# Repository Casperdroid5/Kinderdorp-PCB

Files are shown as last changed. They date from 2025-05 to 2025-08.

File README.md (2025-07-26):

# Kinderdorp PCB 👍

An interactive educational PCB designed for children to learn electronics through hands-on experimentation with LEDs, sensors, and programming.

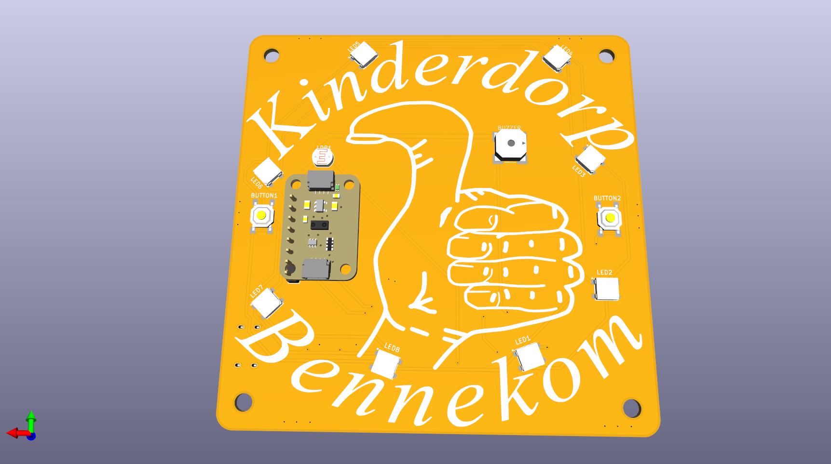
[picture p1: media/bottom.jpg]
Kinderdorp PCB Top

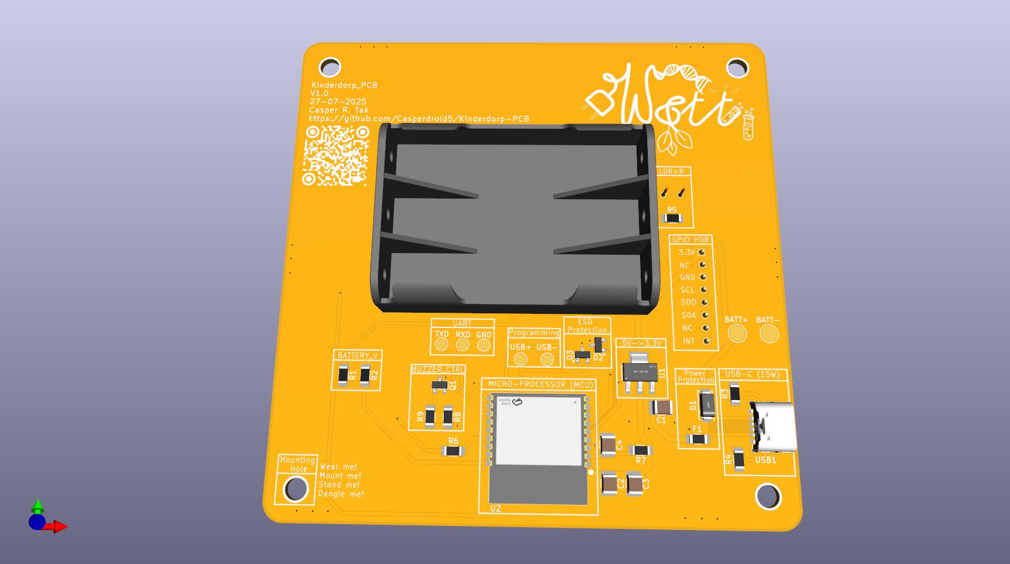
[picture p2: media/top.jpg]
Kinderdorp PCB Bottom


## 📋 Overview

The Kinderdorp PCB is an ESP32-C3 based learning platform featuring addressable RGB LEDs, user input buttons, sensors, and multiple power options. The board includes fun visual elements and is designed to be both educational and engaging for young learners.

## ✨ Features

### 🎯 Core Components
- **ESP32-C3-WROOM-02-N4** microcontroller (4MB Flash)
- **8x WS2812B** addressable RGB LEDs arranged in a creative pattern
- **2x Tactile buttons** for user interaction
- **Light sensor (LDR)** for ambient light detection
- **Buzzer** for audio feedback
- **USB-C connector** for power and programming

### 🔋 Power Options
- **USB-C** power input (5V)
- **Dual CR2032** coin cell battery holders
- **3x AAA** battery pack option
- **AMS1117-3.3V** voltage regulator
- Battery voltage monitoring circuit

### 🔌 Connectivity
- **8-pin header** for expansion and prototyping
- **Programming pins** for development
- **Test points** for debugging

## 🔧 Technical Specifications

| Component | Specification |
|---|---|
| **Microcontroller** | ESP32-C3-WROOM-02-N4 (4MB) |
| **Operating Voltage** | 3.3V |
| **Power Input** | 5V via USB-C or 3-6V battery |
| **LEDs** | 8x WS2812B RGB (5050 package) |
| **Buttons** | 2x DTSM-61R tactile switches |
| **Buzzer** | KSSGK4B16-20 |
| **Light Sensor** | LDR07 photoresistor |
| **PCB Dimensions** | ~100mm x 100mm |

## 📍 Pin Mapping

### GPIO Assignments
```
GPIO0  - Programming/Boot button
GPIO1  - UART TX (programming)
GPIO3  - UART RX (programming)  
GPIO4  - User Button 1
GPIO5  - RGB LED Data Out
GPIO6  - SDA (I2C)
GPIO7  - SCL (I2C)
GPIO8  - User Button 2
GPIO9  - Buzzer Control
GPIO10 - Light Sensor (ADC)
GPIO18 - Battery Voltage Monitor
GPIO19 - RGB LED Data In
```

### LED Chain Order
The 8 WS2812B LEDs are connected in series:
`LED1 → LED2 → LED3 → LED4 → LED5 → LED6 → LED7 → LED8`

## 🚀 Getting Started

### Prerequisites
- **Arduino IDE** or **PlatformIO**
- **ESP32 board package** installed
- **FastLED** or **Adafruit NeoPixel** library for LED control

### Hardware Setup
1. **Power the board** via USB-C or install batteries
2. **Connect** USE the breakout pads USB+ and USB- or UART to program the board
3. **Install** any additional components if using expansion header

### Basic Programming Example

```cpp
#include <FastLED.h>

#define LED_PIN 19
#define NUM_LEDS 8
#define BUTTON1_PIN 4
#define BUTTON2_PIN 8
#define BUZZER_PIN 9
#define LDR_PIN 10

CRGB leds[NUM_LEDS];

void setup() {
  FastLED.addLeds<WS2812B, LED_PIN, GRB>(leds, NUM_LEDS);
  pinMode(BUTTON1_PIN, INPUT_PULLUP);
  pinMode(BUTTON2_PIN, INPUT_PULLUP);
  pinMode(BUZZER_PIN, OUTPUT);
}

void loop() {
  // Rainbow effect
  for(int i = 0; i < NUM_LEDS; i++) {
    leds[i] = CHSV(i * 32, 255, 255);
  }
  FastLED.show();
  delay(100);
}
```

## 🎓 Educational Applications

### Beginner Projects
- **LED Patterns** - Create colorful light sequences
- **Button Response** - Interactive games with button presses
- **Light Detection** - Automatic brightness control
- **Sound Effects** - Musical patterns with the buzzer

### Intermediate Projects
- **Simon Says Game** - Memory game using LEDs and buttons
- **Light Meter** - Display ambient light levels
- **Digital Pet** - Virtual pet with LED expressions
- **Alarm Clock** - Wake-up light with buzzer

### Advanced Projects
- **WiFi Connectivity** - IoT integration and remote control
- **Sensor Dashboard** - Environmental monitoring
- **Interactive Art** - Motion-responsive installations
- **Educational Games** - Programming challenges

## 🔋 Power Management

### Battery Life Optimization
- Use **deep sleep mode** when inactive
- **Dim LEDs** or turn off when not needed
- **Monitor battery voltage** (GPIO18) for low battery warnings

### Battery Voltage Monitoring
```cpp
float getBatteryVoltage() {
  int rawValue = analogRead(18);
  // Voltage divider: 6V→3V, 4.5V→2.25V, 3V→1.5V, 2V→1V
  return (rawValue / 4095.0) * 3.3 * 2.0;
}
```

## 🛠️ Assembly Notes

### Battery Installation
- **Option 1**: Install 2x CR2032 coin cells in BT1 and BT2
- **Option 2**: Connect 3x AAA battery pack to BATTPACK1
- **Do not** install both battery options simultaneously (should not be possible if PCB is asssembled correctly)

## 🎨 Design Features

The PCB includes playful design elements:
- **Artistic patterns** and decorative silkscreen
- **Child-friendly** component layout
- **Clear labeling** for educational purposes
- **Robust construction** for classroom use

## 📄 License

This project is released under the [MIT License](LICENSE). Feel free to use, modify, and distribute for educational purposes.

## 👨‍💻 Author

**Casper R. Tak**

---

*Kinderdorp PCB - Making electronics fun and accessible for young (and older) minds! 🌟*

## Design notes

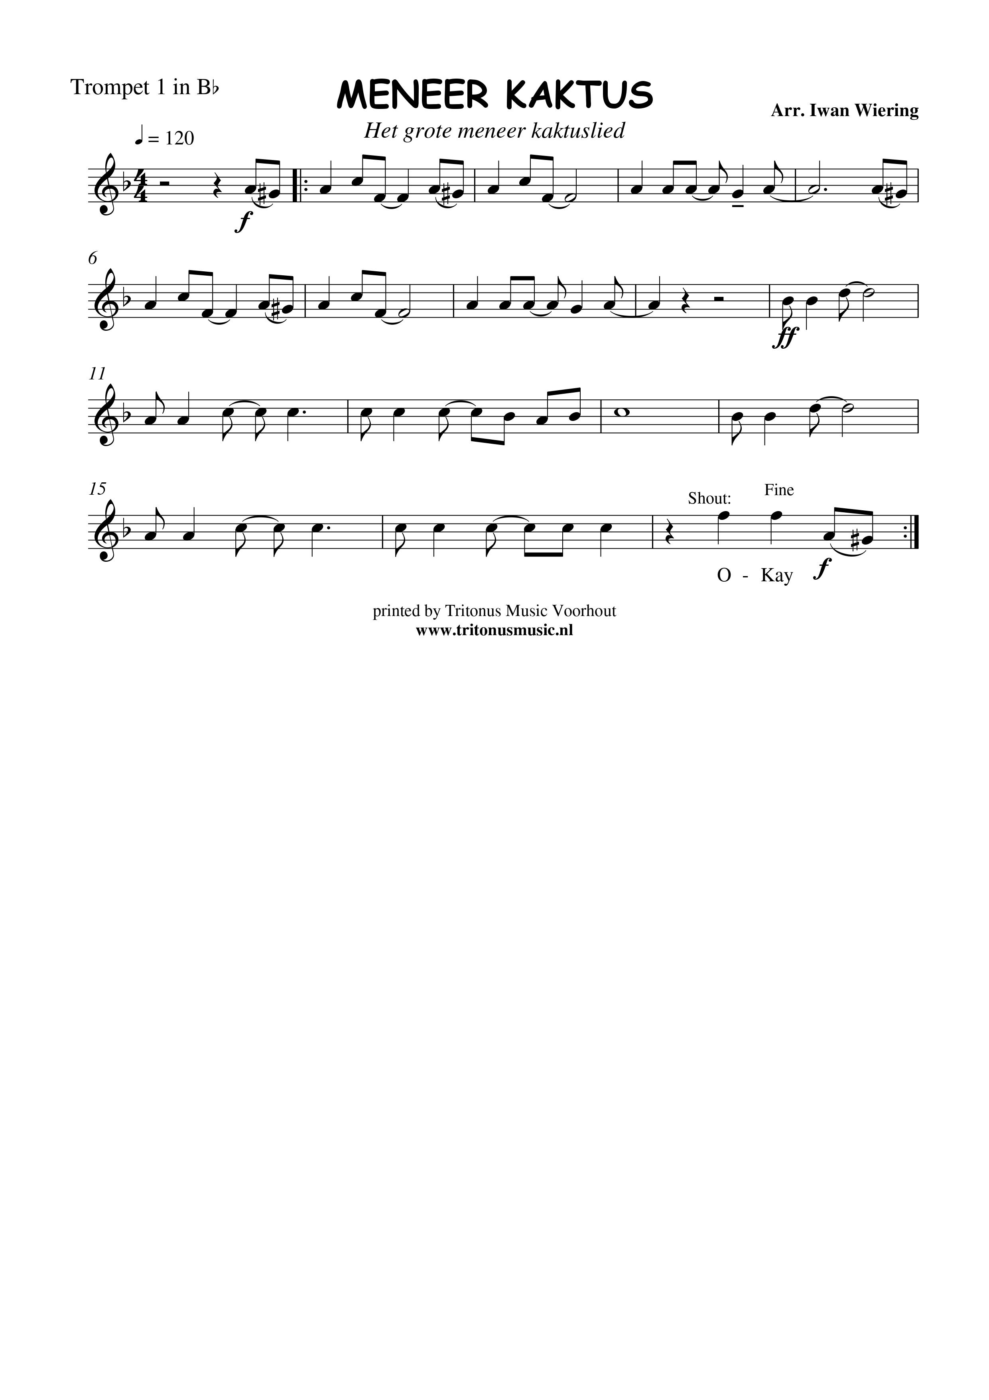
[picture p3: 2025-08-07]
media/Kinderdorp lied/Meneer-kaktus-Trompet-1-in-Bb.jpeg

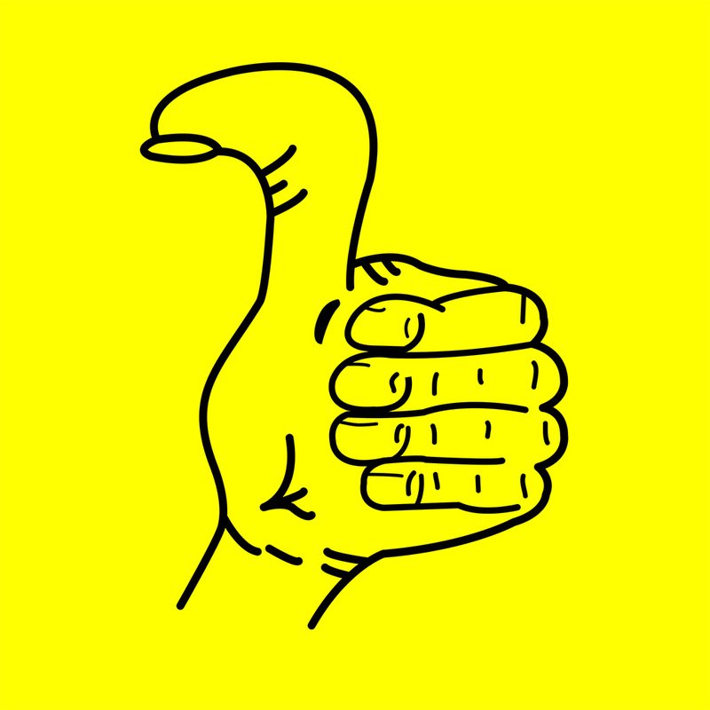
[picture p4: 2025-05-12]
media/kinderdorp logo no text.jpg

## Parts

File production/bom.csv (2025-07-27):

Designator | Footprint | Quantity | Value | LCSC Part #
BATT+ | TestPoint_Pad_D3.0mm | 1 | ~
BATT- | TestPoint_Pad_D3.0mm | 1 | TestPoint_Alt
BT1:, BT2: | BAT-SMD_MY-2032-12 | 2 | MY-2032-12 | C964833
BUTTON1, BUTTON2 | KEY-SMD_4P-L6.2-W6.2-P4.50-LS9.0 | 2 | DTSM-61R-V-T/R | C224977
C1, C3 | 1210 | 2 | 47uF 10V
C2 | 1210 | 1 | 100nF 50V
C4 | 1210 | 1 | 10uF 25V
D1 | SMA_L4.4-W2.6-LS5.0-RD | 1 | 1N5819_C437199 | C437199
D2, D3 | SOT-23 | 2 | SM712_SOT23
F1 | 1206 | 1 | Fuse_Small 2A
GND, RXD, TXD, USB+, USB- | TestPoint_Pad_D2.0mm | 5 | TestPoint_Probe
HDR1 | PinHeader_1x08_P2.54mm_Vertical | 1 | Conn_01x08
LDR1 | R_LDR_5.1x4.3mm_P3.4mm_Vertical | 1 | LDR07
LED1, LED2, LED3, LED4, LED5, LED6, LED7, LED8 | LED-SMD_4P-L5.0-W5.0-BL_TC5050RGB | 8 | WS2812B
LS1 | KSSGK4B16-20 | 1 | KSSGK4B16-20
Q1 | SOT-23-3_L2.9-W1.3-P1.90-LS2.4-BR | 1 | 2N7002_C306856
R1, R2, R7, R8 | 1206 | 4 | 10k
R3, R4 | 1206 | 2 | 5k1
R5 | 1206 | 1 | 5k
R6, R9 | 1206 | 2 | 200
U1 | SOT-223-4_L6.5-W3.5-P2.30-LS7.0-BR | 1 | AMS1117-3.3_C347222 | C347222
U2 | BULETM-SMD_ESPRESSIF_ESP32-C3-WROOM-02-N4-4MB | 1 | ESP32-C3-WROOM-02-N4(4MB)
USB1 | TYPE-C-SMD_TYPE-C-6P_5 | 1 | TYPE-C 6P(073) | C668623

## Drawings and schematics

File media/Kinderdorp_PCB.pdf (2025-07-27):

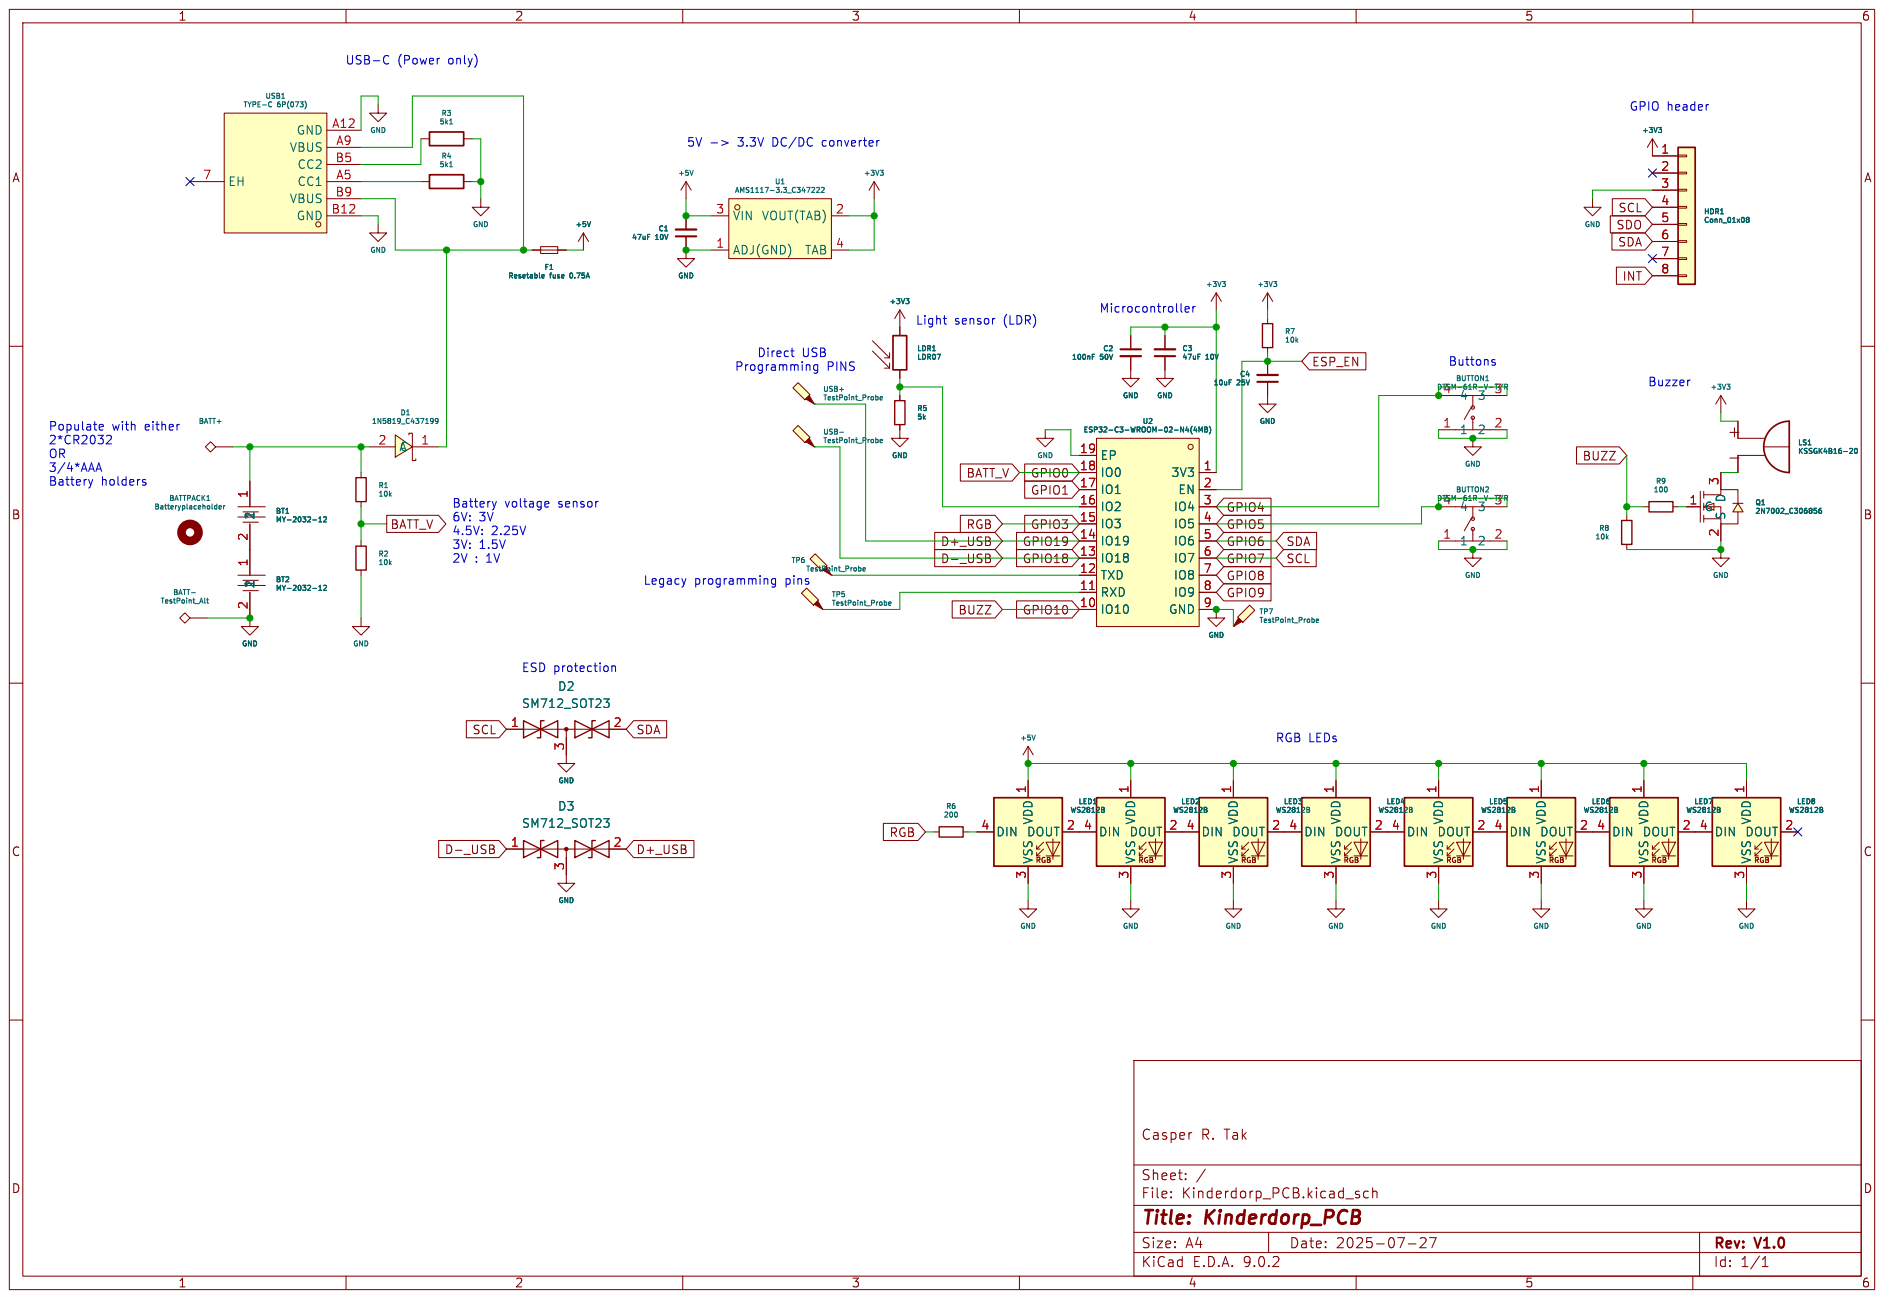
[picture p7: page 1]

5k1 GND B12 VBUS B9 CC1 A5 CC2 B5 VBUS A9 GND A12 EH 7

File: Kinderdorp_PCB.kicad_sch Sheet: / Casper R. Tak

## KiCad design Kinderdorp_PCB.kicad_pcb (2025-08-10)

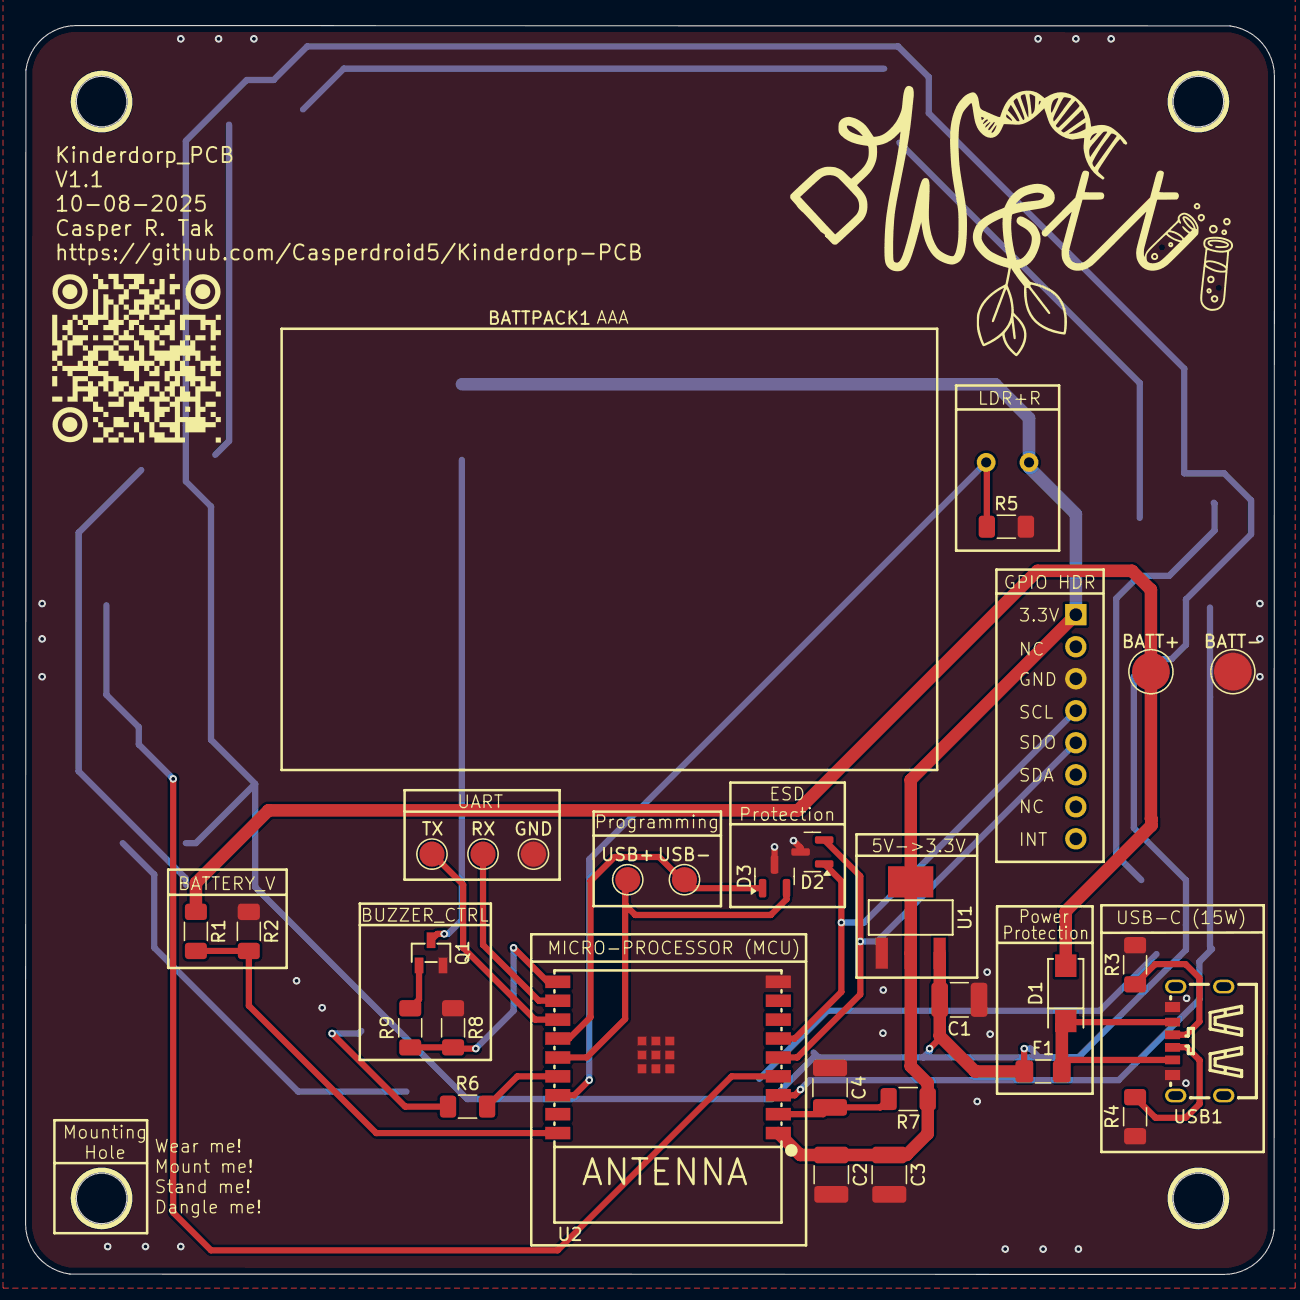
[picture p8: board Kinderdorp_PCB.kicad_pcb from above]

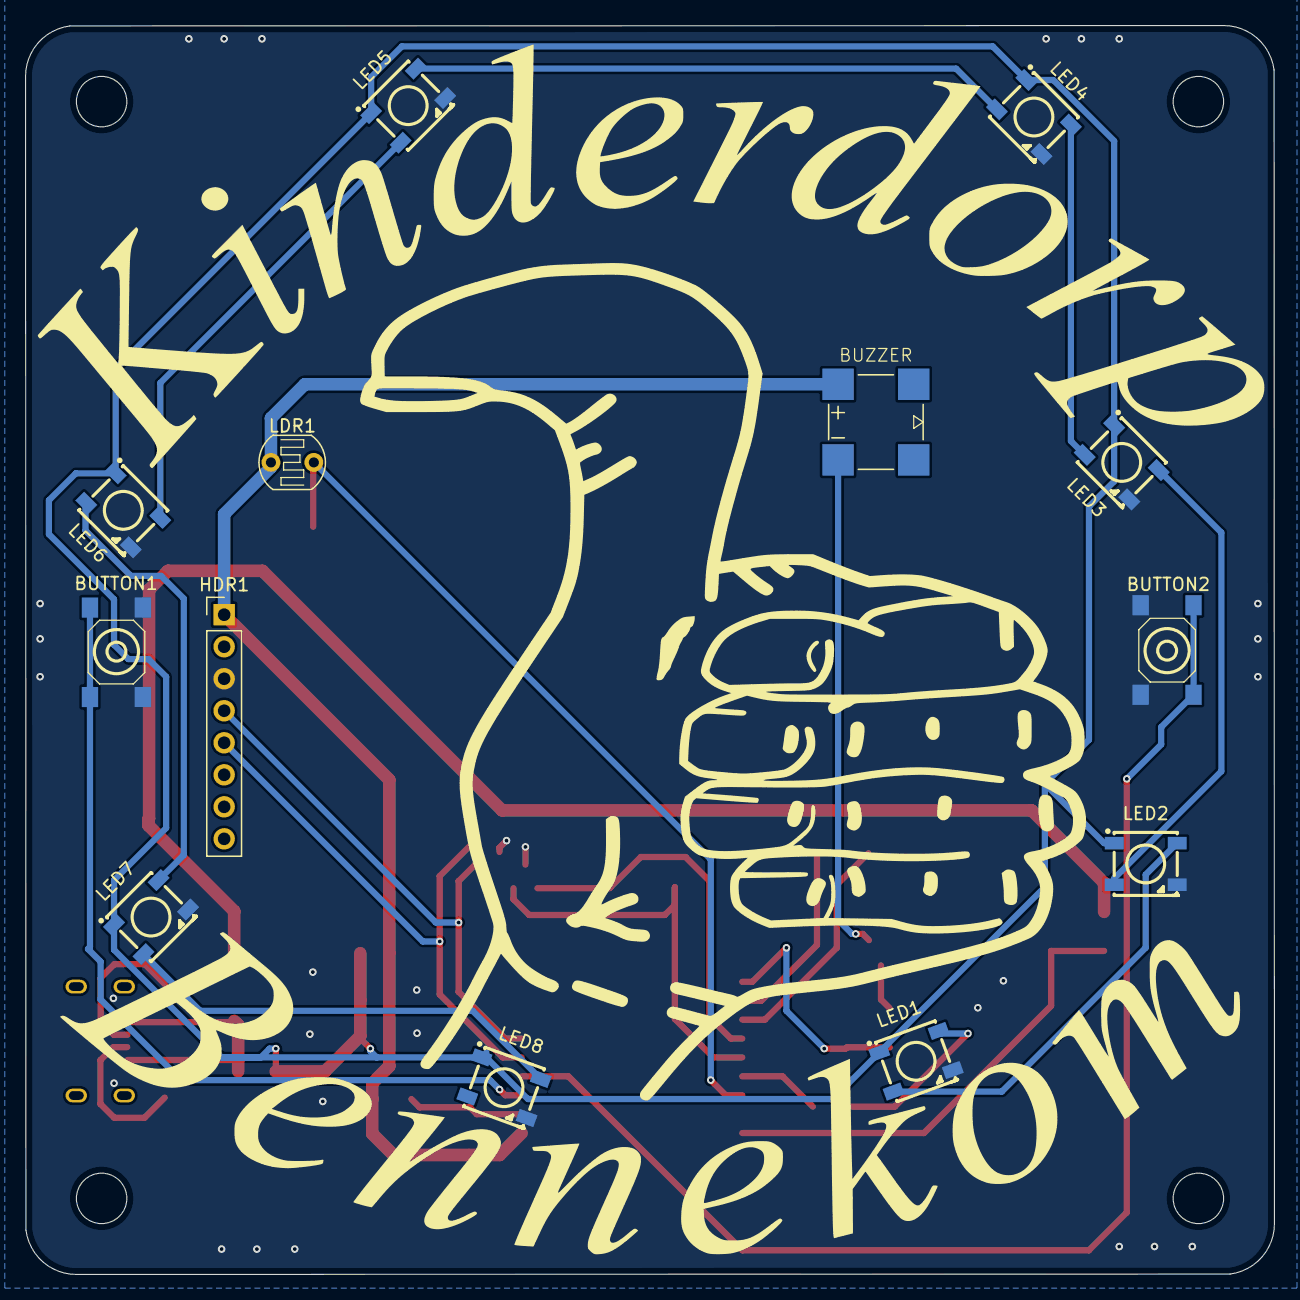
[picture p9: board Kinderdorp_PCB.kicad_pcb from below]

Board: 2 copper layers, 99.1 x 99.1 mm, 42 parts (13 on the bottom side), 30 nets.

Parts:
BATT+: TestPoint_Pad_D3.0mm
BATT-: TestPoint_Alt; TestPoint_Pad_D3.0mm
BATTPACK1: Batteryplaceholder; MountingHole_2.1mm
BUTTON1, BUTTON2: DTSM-61R-V-T/R; KEY-SMD_4P-L6.2-W6.2-P4.50-LS9.0
C1, C3: 47uF 10V; C_1210_3225Metric_Pad1.33x2.70mm_HandSolder
C2: 100nF 50V; C_1210_3225Metric_Pad1.33x2.70mm_HandSolder
C4: 10uF 25V; C_1210_3225Metric_Pad1.33x2.70mm_HandSolder
D1: 1N5819_C437199; SMA_L4.4-W2.6-LS5.0-RD
D2, D3: SM712_SOT23; SOT-23
F1: Resetable fuse 0.75A; Fuse_1206_3216Metric_Pad1.42x1.75mm_HandSolder
GND: TestPoint_Probe; TestPoint_Pad_D2.0mm
HDR1: Conn_01x08; PinHeader_1x08_P2.54mm_Vertical
LDR1: LDR07; R_LDR_5.1x4.3mm_P3.4mm_Vertical
LED1, LED2, LED3, LED4, LED5, LED6, LED7, LED8: WS2812B; LED-SMD_4P-L5.0-W5.0-BL_TC5050RGB
LS1: KSSGK4B16-20
Q1: 2N7002_C306856; SOT-23-3_L2.9-W1.3-P1.90-LS2.4-BR
R1, R2, R7, R8: 10k; R_1206_3216Metric_Pad1.30x1.75mm_HandSolder
R3, R4: 5k1; R_1206_3216Metric_Pad1.30x1.75mm_HandSolder
R5: 5k; R_1206_3216Metric_Pad1.30x1.75mm_HandSolder
R6: 200; R_1206_3216Metric_Pad1.30x1.75mm_HandSolder
R9: 100; R_1206_3216Metric_Pad1.30x1.75mm_HandSolder
RX: TestPoint_Probe; TestPoint_Pad_D2.0mm
TX: TestPoint_Probe; TestPoint_Pad_D2.0mm
U1: AMS1117-3.3_C347222; SOT-223-4_L6.5-W3.5-P2.30-LS7.0-BR
U2: ESP32-C3-WROOM-02-N4(4MB); BULETM-SMD_ESPRESSIF_ESP32-C3-WROOM-02-N4-4MB
USB1: TYPE-C 6P(073); TYPE-C-SMD_TYPE-C-6P_5
USB+: TestPoint_Probe; TestPoint_Pad_D2.0mm
USB-: TestPoint_Probe; TestPoint_Pad_D2.0mm

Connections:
+3V3: C2.1, C3.2, HDR1.1, LDR1.1, LS1.P, R7.1, U1.2 (VOUT(TAB)), U1.4 (TAB), U2.1 (3V3)
+5V: C1.2, F1.1, LED1.1 (VDD), LED2.1 (VDD), LED3.1 (VDD), LED4.1 (VDD), LED5.1 (VDD), LED6.1 (VDD), LED7.1 (VDD), LED8.1 (VDD), U1.3 (VIN)
BATT_V: R1.2, R2.1, U2.18 (IO0)
BUZZ: R8.2, R9.1, U2.10 (IO10)
D+_USB: D3.2 (A2), U2.14 (IO19), USB+.1
D-_USB: D3.1 (A1), U2.13 (IO18), USB-.1
ESP_EN: C4.2, R7.2, U2.2 (EN)
GND: BATT-.1, BUTTON1.2, BUTTON1.4, BUTTON2.2, BUTTON2.4, C1.1, C2.2, C3.1, C4.1, D2.3 (common), D3.3 (common), GND.1, HDR1.3, LED1.3 (VSS), LED2.3 (VSS), LED3.3 (VSS), LED4.3 (VSS), LED5.3 (VSS), LED6.3 (VSS), LED7.3 (VSS), LED8.3 (VSS), Q1.2 (S), R2.2, R3.1, R4.1, R5.2, R8.1, U1.1 (ADJ(GND)), U2.9 (GND), U2.19 (EP), USB1.A12 (GND), USB1.B12 (GND)
GPIO3: R6.2, U2.15 (IO3)
GPIO4: BUTTON1.1, BUTTON1.3, U2.3 (IO4)
GPIO5: BUTTON2.1, BUTTON2.3, U2.4 (IO5)
GPIO6: D2.2 (A2), HDR1.5, U2.5 (IO6)
GPIO7: D2.1 (A1), HDR1.4, U2.6 (IO7)
unnamed: BATT+.1, D1.2 (A), R1.1
unnamed: D1.1 (C), F1.2, USB1.A9 (VBUS), USB1.B9 (VBUS)
unnamed: LED1.4 (DIN), R6.1
unnamed: LED1.2 (DOUT), LED2.4 (DIN)
unnamed: LED2.2 (DOUT), LED3.4 (DIN)
unnamed: LED3.2 (DOUT), LED4.4 (DIN)
unnamed: LED4.2 (DOUT), LED5.4 (DIN)
unnamed: LED5.2 (DOUT), LED6.4 (DIN)
unnamed: LED6.2 (DOUT), LED7.4 (DIN)
unnamed: LED7.2 (DOUT), LED8.4 (DIN)
unnamed: LS1.N, Q1.3 (D)
unnamed: Q1.1 (G), R9.2
unnamed: LDR1.2, R5.1, U2.16 (IO2)
unnamed: RX.1, U2.11 (RXD)
unnamed: TX.1, U2.12 (TXD)
unnamed: R4.2, USB1.A5 (CC1)
unnamed: R3.2, USB1.B5 (CC2)

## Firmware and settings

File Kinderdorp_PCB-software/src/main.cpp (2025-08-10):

#include <Arduino.h>  // Required for PlatformIO
#include <FastLED.h>
#include <Preferences.h>

// Preferences object for storing settings
Preferences preferences;

// Hardware Configuration - Updated for new PCB
const int BUZZER = 10;      // Buzzer pin (GPIO10)
#define RGB_PIN 3      // Data pin for LED strip (GPIO3)

#include "kinderdorp_song.h"  // Include after BUZZER definition
#define BUTTON1 4      // Button 1 pin (GPIO4) - change color/pattern
#define BUTTON2 5      // Button 2 pin (GPIO5) - play song
#define BATT_SENSE 0   // Battery voltage sensing pin (GPIO0)
#define LDR_PIN 2      // Light sensor pin (GPIO2)
#define NUM_LEDS 8     // Total number of LEDs (based on schematic)

// Battery voltage thresholds (after voltage divider: actual voltage = reading * 2)
#define BATT_MIN 1.8           // Minimum battery voltage
#define BATT_MAX 3.5           // Maximum battery voltage  
#define BATT_NO_DETECT 0.5     // Below this = no battery detected

// Brightness levels based on power source - matching Christmas lights
#define BRIGHTNESS_USB 128     // 50% brightness for USB power (128/255 = 50%)
#define BRIGHTNESS_BATTERY 40  // 15% brightness for battery power (40/255 = 15%)

// LDR Configuration
#define LDR_THRESHOLD 1200      // Lower threshold - considered dark below this value
#define LDR_HYSTERESIS 200      // Prevents flickering by adding hysteresis
#define LDR_CHECK_INTERVAL 1000 // Check LDR every 1 second

// LED Array
CRGB leds[NUM_LEDS];

// Button Handling
bool button1State = HIGH;
bool lastButton1State = HIGH;
bool button2State = HIGH;
bool lastButton2State = HIGH;
unsigned long lastDebounceTime = 0;
unsigned long debounceDelay = 50;

// Power Management
enum PowerSource {
  POWER_USB,
  POWER_BATTERY
};
PowerSource currentPowerSource = POWER_USB;
int currentBrightness = BRIGHTNESS_USB;
bool wifiEnabled = true;

// Light Sensor Management (LDR reading only for status display)
int lastLDRReading = 0;

// Display Mode Enum
enum DisplayMode {
  STATIC_COLOR,
  RAINBOW_MODE,
  SNAKE_MODE,
  RANDOM_BLINK,
  CHASE_MODE,
  BREATHE_MODE,
  WAVE_MODE,
  SPARKLE_MODE,      // Twinkling effect
  FIREWORK_MODE,     // Exploding pattern
  METEOR_MODE,       // Shooting star effect
  CANDY_CANE_MODE,   // Rotating stripes
  FADE_RANDOM,       // Fading patterns
  RANDOM_SCATTER,    // Random red/green pattern
  OFF_MODE
};

DisplayMode currentMode = STATIC_COLOR;

// Color Options (Used for STATIC_COLOR mode)
int currentColorIndex = 0;
// Color definitions for LED patterns
CRGB colorOptions[] = {
  CRGB::Red,
  CRGB::Green,
  CRGB::Blue,
  CRGB::Purple,
  CRGB::Yellow,
  CRGB::Cyan,
  CRGB::White,
  CRGB::Orange,
  CRGB::Pink,
  CRGB::Magenta,
  CRGB::Lime,
  CRGB::Aqua,
  CRGB::Indigo,
  CRGB::Violet,
  CRGB::Gold,
  CRGB::Silver
};
#define NUM_COLORS (sizeof(colorOptions) / sizeof(colorOptions[0]))

// Pattern Variables
unsigned long lastPatternUpdate = 0;
unsigned long patternUpdateInterval = 50;

// Pattern-specific speed controls (adjusted for battery life)
const unsigned long RAINBOW_SPEED = 150;   // Slower to save power
const unsigned long SNAKE_SPEED = 200;     // Slower snake movement
const unsigned long CHASE_SPEED = 180;     // Slower chase pattern
const unsigned long WAVE_SPEED = 120;      // Slower wave
const unsigned long BREATHE_SPEED = 40;    // Slower breathe
const unsigned long SPARKLE_SPEED = 200;   // Sparkle timing
const unsigned long FIREWORK_SPEED = 400;  // Firework timing
const unsigned long METEOR_SPEED = 200;    // Meteor timing
const unsigned long CANDY_SPEED = 600;     // Candy cane timing
const unsigned long FADE_SPEED = 200;      // Fade timing
const unsigned long SCATTER_SPEED = 1000;  // Random scatter timing

// Snake Pattern Variables
uint8_t snakeHeadPos = 0;
const uint8_t snakeLength = 3;  // Shorter snake for 8 LEDs
uint8_t snakeHue = 0;

// Random Blink Variables
uint8_t randomLEDs[3] = {0};    // Fewer active LEDs for power saving
uint8_t randomHues[3] = {0};
unsigned long randomBlinkInterval = 600;
unsigned long lastRandomUpdate = 0;

// Chase Pattern Variables
uint8_t chasePos = 0;
uint8_t chaseHue = 0;

// Breathe Pattern Variables
uint8_t breatheBrightness = 0;
bool breatheIncreasing = true;
uint8_t breatheHue = 0;

// Wave Pattern Variables
uint8_t waveOffset = 0;
uint8_t waveHue = 0;

// Sparkle Pattern Variables
uint8_t sparklePositions[NUM_LEDS];
uint8_t sparkleBrightness[NUM_LEDS];
uint8_t sparkleColors[NUM_LEDS];

// Firework Pattern Variables
struct Firework {
    int8_t position;
    uint8_t phase;  // 0=launch, 1=explode, 2=fade
    uint8_t brightness;
    uint8_t color;
};
Firework currentFirework = {-1, 0, 0, 0};

// Meteor Pattern Variables
int8_t meteorPos = -1;
uint8_t meteorTail[3];
uint8_t meteorColor = 0;

// Candy Cane Pattern Variables
uint8_t candyOffset = 0;
uint8_t stripeWidth = 2;

// Fade pattern variables
uint8_t fadeProgress = 0;
CRGB currentFadeColors[NUM_LEDS];
CRGB targetFadeColors[NUM_LEDS];
bool needNewFadeTarget = true;

// Song State and Variables (implemented in kinderdorp_song.cpp)
// Variables are declared as extern in kinderdorp_song.h

// Battery monitoring
unsigned long lastBatteryCheck = 0;
const unsigned long batteryCheckInterval = 10000; // Check every 10 seconds

// Settings and Uptime Management
bool settingsChanged = false;
unsigned long lastSaveTime = 0;
const unsigned long saveInterval = 30000; // Save every 30 seconds if needed

// Uptime tracking (64-bit for extended duration)
uint32_t totalUptimeLow = 0;   // Lower 32 bits of uptime in seconds
uint32_t totalUptimeHigh = 0;  // Upper 32 bits of uptime in seconds
unsigned long lastMillisCheck = 0; // For millis() overflow detection

// Function prototypes
void checkPowerSource();
bool shouldShowLEDs();
void printPowerStatus();
void checkButtons();
void handleButton1Press();
void handleButton2Press();
void updatePatterns();
void updateRainbowPattern();
void updateSnakePattern();
void updateRandomBlinkPattern(unsigned long currentTime);
void updateChasePattern();
void updateBreathePattern();
void updateWavePattern();
void updateSparklePattern();
void updateFireworkPattern();
void updateMeteorPattern();
void updateCandyCanePattern();
void updateFadeRandom();
void updateRandomScatter();
void turnOffAllLEDs();
void updateDisplay();
void startSong();
void updateSong();
void markSettingsChanged();
void saveToMemory();
void loadSettings();

// Function to mark settings as changed
void markSettingsChanged() {
    settingsChanged = true;
}

// Combined function to save settings and uptime if needed
void saveToMemory() {
    unsigned long currentMillis = millis();
    
    // Check for millis() overflow
    if (currentMillis < lastSaveTime) {
        // millis() has overflowed, force a save
        lastSaveTime = currentMillis;
    }
    
    // Only save if enough time has passed since last save and changes exist
    if (currentMillis - lastSaveTime >= saveInterval && settingsChanged) {
        preferences.begin("kinderdorp", false);  // Open preferences in RW mode
        
        // Save settings
        preferences.putUChar("displayMode", (uint8_t)currentMode);
        preferences.putUChar("colorIndex", currentColorIndex);
        
        // Save 64-bit uptime as two 32-bit values
        preferences.putULong("uptimeLow", totalUptimeLow);
        preferences.putULong("uptimeHigh", totalUptimeHigh);
        
        preferences.end();
        
        lastSaveTime = currentMillis;
        settingsChanged = false;
        Serial.println("Settings and uptime saved to memory");
    }
}

// Function to load settings from non-volatile memory
void loadSettings() {
  preferences.begin("kinderdorp", true);  // Open preferences in read-only mode
  
  // Load display mode with STATIC_COLOR as default
  currentMode = (DisplayMode)preferences.getUChar("displayMode", STATIC_COLOR);
  
  // Load color index with 0 (Red) as default
  currentColorIndex = preferences.getUChar("colorIndex", 0);
  
  // Load 64-bit uptime from two 32-bit values
  totalUptimeLow = preferences.getULong("uptimeLow", 0);
  totalUptimeHigh = preferences.getULong("uptimeHigh", 0);
  
  preferences.end();
  
  // Initialize millis() overflow detection
  lastMillisCheck = millis();
  
  Serial.println("Settings loaded from memory:");
  Serial.print("Display Mode: ");
  Serial.println((int)currentMode);
  Serial.print("Color Index: ");
  Serial.println(currentColorIndex);
  
  // Calculate total seconds for display
  uint64_t totalSeconds = ((uint64_t)totalUptimeHigh << 32) | totalUptimeLow;
  Serial.print("Total Device Uptime: ");
  Serial.print(totalSeconds / 86400); // Days
  Serial.print(" days, ");
  Serial.print((totalSeconds % 86400) / 3600); // Hours
  Serial.print(" hours, ");
  Serial.print((totalSeconds % 3600) / 60); // Minutes
  Serial.print(" minutes, ");
  Serial.print(totalSeconds % 60); // Seconds
  Serial.println(" seconds");
}

void setup() {
  Serial.begin(115200);
  Serial.println("Starting...");
  
  // Initialize hardware
  pinMode(BUZZER, OUTPUT);
  pinMode(BUTTON1, INPUT_PULLUP);
  pinMode(BUTTON2, INPUT_PULLUP);
  pinMode(BATT_SENSE, INPUT);
  pinMode(LDR_PIN, INPUT);
  
  // Check initial power source
  checkPowerSource();
  
  // Initialize LEDs with appropriate brightness
  FastLED.addLeds<WS2812B, RGB_PIN, GRB>(leds, NUM_LEDS);
  FastLED.setBrightness(currentBrightness);
  
  // Load saved settings from memory
  loadSettings();
  
  // Initial state
  updateDisplay();
  
  Serial.println("Ready!");
  printPowerStatus();
}

void loop() {
  static unsigned long lastHeartbeat = 0;
  static unsigned long sessionUptime = 0;
  
  // Check for uptime overflow and update running total
  unsigned long currentMillis = millis();
  if (currentMillis < lastMillisCheck) {
    // Overflow detected - add the previous maximum value
    unsigned long long newTime = (unsigned long long)totalUptimeLow + 0xFFFFFFFF;
    if (newTime < (unsigned long long)totalUptimeLow) {
      // Overflow in low part, increment high part
      totalUptimeHigh++;
      totalUptimeLow = currentMillis;
    } else {
      totalUptimeLow = (unsigned long)newTime;
    }
  }
  lastMillisCheck = currentMillis;
  
  // Save settings every 30 seconds if changed
  static unsigned long lastSaveTime = 0;
  if (settingsChanged && (currentMillis - lastSaveTime) > 30000) {
    saveToMemory();
    lastSaveTime = currentMillis;
  }
  
  // Heartbeat message every 3 seconds with prettier formatting
  if (currentMillis - lastHeartbeat >= 3000) {
    sessionUptime += 3;
    lastHeartbeat = currentMillis;
    
    // Read sensor values
    int ldrReading = analogRead(LDR_PIN);
    int battReading = analogRead(BATT_SENSE);
    float battVoltage = (battReading / 4095.0) * 3.3 * 2; // Actual voltage after divider
    
    Serial.println("\n=== Kinderdorp Status ===");
    Serial.print("⏱️  Uptime: ");
    Serial.print(sessionUptime / 60);
    Serial.print("m ");
    Serial.print(sessionUptime % 60);
    Serial.println("s");
    
    Serial.print("🎨 Mode: ");
    switch(currentMode) {
      case STATIC_COLOR: 
        Serial.print("Static ");
        Serial.print(currentColorIndex < NUM_COLORS ? (currentColorIndex == 0 ? "Red" : currentColorIndex == 1 ? "Green" : "Blue") : "Unknown");
        break;
      case RAINBOW_MODE: Serial.print("Rainbow"); break;
      case SNAKE_MODE: Serial.print("Snake"); break;
      case RANDOM_BLINK: Serial.print("Random Blink"); break;
      case CHASE_MODE: Serial.print("Chase"); break;
      case BREATHE_MODE: Serial.print("Breathe"); break;
      case WAVE_MODE: Serial.print("Wave"); break;
      case SPARKLE_MODE: Serial.print("Sparkle"); break;
      case FIREWORK_MODE: Serial.print("Firework"); break;
      case METEOR_MODE: Serial.print("Meteor"); break;
      case CANDY_CANE_MODE: Serial.print("Candy Cane"); break;
      case FADE_RANDOM: Serial.print("Fade Random"); break;
      case RANDOM_SCATTER: Serial.print("Random Scatter"); break;
      case OFF_MODE: Serial.print("OFF"); break;
    }
    Serial.println();
    
    Serial.print("💡 LEDs: ");
    Serial.print(shouldShowLEDs() ? "ON" : "OFF");
    Serial.print(" (Brightness: ");
    Serial.print((currentBrightness * 100) / 255);
    Serial.println("%)");
    
    if (songState == PLAYING_SONG) {
      Serial.print("🎵 Playing: Step ");
      Serial.print(songStep);
      Serial.println("/139");
    } else {
      Serial.println("🎵 Song: Ready");
    }
    
    Serial.print("🌅 Light: ");
    Serial.print(ldrReading);
    Serial.print(" (");
    Serial.print(ldrReading < LDR_THRESHOLD ? "Dark" : "Bright");
    Serial.println(")");
    
    Serial.print("🔋 Power: ");
    Serial.print(currentPowerSource == POWER_USB ? "USB" : "Battery");
    Serial.print(" - ");
    Serial.print(battVoltage, 2);
    Serial.println("V");
    
    Serial.println("========================\n");
  }
  
  checkButtons();
  updateSong();
  
  // Check if LEDs should be shown based on light sensor and force enable status
  if (shouldShowLEDs()) {
    updatePatterns();
  } else {
    // Turn off LEDs when it's too bright (unless song is playing)
    if (songState == IDLE) {
      turnOffAllLEDs();
    } else {
      updatePatterns(); // Always show LEDs during song
    }
  }
  
  // Periodic monitoring
  if (millis() - lastBatteryCheck > batteryCheckInterval) {
    checkPowerSource();
    lastBatteryCheck = millis();
  }
  
  FastLED.show();
}

void checkPowerSource() {
  // Read battery voltage (voltage divider gives us half the actual voltage)
  int reading = analogRead(BATT_SENSE);
  float voltage = (reading / 4095.0) * 3.3; // Convert to voltage
  
  PowerSource oldPowerSource = currentPowerSource;
  
  if (voltage < BATT_NO_DETECT) {
    // No battery detected - running on USB
    currentPowerSource = POWER_USB;
    currentBrightness = BRIGHTNESS_USB;
    wifiEnabled = true;
  } else if (voltage >= BATT_MIN && voltage <= BATT_MAX) {
    // Battery detected
    currentPowerSource = POWER_BATTERY;
    currentBrightness = BRIGHTNESS_BATTERY;
    wifiEnabled = false;
  } else {
    // Unknown voltage - assume battery power for safety
    currentPowerSource = POWER_BATTERY;
    currentBrightness = BRIGHTNESS_BATTERY;
    wifiEnabled = false;
  }
  
  // Update brightness if power source changed
  if (oldPowerSource != currentPowerSource) {
    FastLED.setBrightness(currentBrightness);
    printPowerStatus();
    
    // Disable WiFi/Bluetooth for battery operation
    if (!wifiEnabled) {
      // Add WiFi disable code here if needed
      Serial.println("WiFi disabled");
    }
  }
}

bool shouldShowLEDs() {
  // Always show LEDs unless in OFF_MODE
  return currentMode != OFF_MODE;
}

void printPowerStatus() {
  Serial.print("Power Source: ");
  switch (currentPowerSource) {
    case POWER_USB:
      Serial.print("USB");
      break;
    case POWER_BATTERY:
      Serial.print("Battery");
      break;
  }
  Serial.print(", Brightness: ");
  Serial.print((currentBrightness * 100) / 255);
  Serial.print("%, Light Level: ");
  Serial.print(lastLDRReading);
  Serial.print(", LEDs: ");
  Serial.println(shouldShowLEDs() ? "Enabled" : "Disabled");
}

void checkButtons() {
  bool reading1 = digitalRead(BUTTON1);
  bool reading2 = digitalRead(BUTTON2);

  // Debounce logic
  if (reading1 != lastButton1State || reading2 != lastButton2State) {
    lastDebounceTime = millis();
  }

  if ((millis() - lastDebounceTime) > debounceDelay) {
    // Button 1 - Change mode/color
    if (reading1 != button1State) {
      button1State = reading1;
      if (button1State == LOW) {
        handleButton1Press();
      }
    }

    // Button 2 - Play song
    if (reading2 != button2State) {
      button2State = reading2;
      if (button2State == LOW) {
        handleButton2Press();
      }
    }
  }

  lastButton1State = reading1;
  lastButton2State = reading2;
}

void handleButton1Press() {
  // Enable LEDs for better visibility when adjusting
  
  if (currentMode == STATIC_COLOR) {
    currentColorIndex = (currentColorIndex + 1) % NUM_COLORS;
    if (currentColorIndex == NUM_COLORS - 1) {
      // After going through all colors, switch to first pattern mode
      currentMode = RAINBOW_MODE;
      Serial.println("RAINBOW");
    } else {
      Serial.println(currentColorIndex);
    }
  } else {
    // Switch to next pattern mode
    currentMode = (DisplayMode)((int)currentMode + 1);
    if (currentMode > OFF_MODE) {
      currentMode = STATIC_COLOR;
      currentColorIndex = 0;
      Serial.println("STATIC");
    } else {
      Serial.println((int)currentMode);
    }
  }
  
  // Mark settings as changed for memory save
  markSettingsChanged();
  updateDisplay();
}

void handleButton2Press() {
  // Songs always play regardless of light conditions
  if (songState == IDLE) {
    startSong();
  } else {
    stopSong();
  }
}

void updatePatterns() {
  unsigned long currentTime = millis();
  
  if (songState != IDLE) return; // Don't update patterns while playing song
  
  // Set update interval based on current mode
  switch (currentMode) {
    case RAINBOW_MODE:
      patternUpdateInterval = RAINBOW_SPEED;
      break;
    case SNAKE_MODE:
      patternUpdateInterval = SNAKE_SPEED;
      break;
    case CHASE_MODE:
      patternUpdateInterval = CHASE_SPEED;
      break;
    case WAVE_MODE:
      patternUpdateInterval = WAVE_SPEED;
      break;
    case BREATHE_MODE:
      patternUpdateInterval = BREATHE_SPEED;
      break;
    case SPARKLE_MODE:
      patternUpdateInterval = SPARKLE_SPEED;
      break;
    case FIREWORK_MODE:
      patternUpdateInterval = FIREWORK_SPEED;
      break;
    case METEOR_MODE:
      patternUpdateInterval = METEOR_SPEED;
      break;
    case CANDY_CANE_MODE:
      patternUpdateInterval = CANDY_SPEED;
      break;
    case FADE_RANDOM:
      patternUpdateInterval = FADE_SPEED;
      break;
    case RANDOM_SCATTER:
      patternUpdateInterval = SCATTER_SPEED;
      break;
    case RANDOM_BLINK:
      // Uses its own timing
      break;
    default:
      patternUpdateInterval = 50;
      break;
  }
  
  if (currentTime - lastPatternUpdate >= patternUpdateInterval) {
    lastPatternUpdate = currentTime;
    
    switch (currentMode) {
      case STATIC_COLOR:
        // No animation needed
        break;
      case RAINBOW_MODE:
        updateRainbowPattern();
        break;
      case SNAKE_MODE:
        updateSnakePattern();
        break;
      case RANDOM_BLINK:
        updateRandomBlinkPattern(currentTime);
        break;
      case CHASE_MODE:
        updateChasePattern();
        break;
      case BREATHE_MODE:
        updateBreathePattern();
        break;
      case WAVE_MODE:
        updateWavePattern();
        break;
      case SPARKLE_MODE:
        updateSparklePattern();
        break;
      case FIREWORK_MODE:
        updateFireworkPattern();
        break;
      case METEOR_MODE:
        updateMeteorPattern();
        break;
      case CANDY_CANE_MODE:
        updateCandyCanePattern();
        break;
      case FADE_RANDOM:
        updateFadeRandom();
        break;
      case RANDOM_SCATTER:
        updateRandomScatter();
        break;
      case OFF_MODE:
        turnOffAllLEDs();
        break;
    }
  }
}

void updateRainbowPattern() {
  breatheHue += 2; // Faster color transition
  for (int i = 0; i < NUM_LEDS; i++) {
    // Create a more vibrant rainbow with offset per LED
    int hue = (breatheHue + (i * 32)) % 255; // More spread between LEDs
    leds[i] = CHSV(hue, 255, 255);
  }
}

void updateSnakePattern() {
  turnOffAllLEDs();
  
  snakeHeadPos = (snakeHeadPos + 1) % NUM_LEDS;
  snakeHue += 3; // Faster color change
  
  for (int i = 0; i < snakeLength; i++) {
    int pos = (snakeHeadPos - i + NUM_LEDS) % NUM_LEDS;
    int brightness = 255 - (i * 200 / snakeLength); // Keep tail brighter
    // Use current color selection for snake
    leds[pos] = colorOptions[currentColorIndex];
    leds[pos].fadeToBlackBy(255 - brightness);
  }
}

void updateRandomBlinkPattern(unsigned long currentTime) {
  if (currentTime - lastRandomUpdate >= randomBlinkInterval) {
    lastRandomUpdate = currentTime;
    
    // Turn off old random LEDs with fade
    for (int i = 0; i < 3; i++) {
      if (randomLEDs[i] < NUM_LEDS) {
        leds[randomLEDs[i]].fadeToBlackBy(180);
      }
    }
    
    // Generate new random LEDs with random colors from our palette
    for (int i = 0; i < 3; i++) {
      randomLEDs[i] = random8(0, NUM_LEDS);
      leds[randomLEDs[i]] = colorOptions[random(NUM_COLORS)];
    }
  }
}

void updateChasePattern() {
  // Fade all LEDs instead of turning off completely
  fadeToBlackBy(leds, NUM_LEDS, 100);
  
  // Create a comet tail effect
  for (int i = 0; i < 3; i++) {
    int pos = (chasePos - i + NUM_LEDS) % NUM_LEDS;
    int brightness = 255 - (i * 80);
    leds[pos] = colorOptions[currentColorIndex];
    leds[pos].fadeToBlackBy(255 - brightness);
  }
  
  chasePos = (chasePos + 1) % NUM_LEDS;
}

void updateBreathePattern() {
  if (breatheIncreasing) {
    breatheBrightness += 4; // Smoother breathing
    if (breatheBrightness >= 255) {
      breatheIncreasing = false;
    }
  } else {
    breatheBrightness -= 4;
    if (breatheBrightness <= 20) { // Don't go completely black
      breatheIncreasing = true;
      // Cycle through all our colors
      currentColorIndex = (currentColorIndex + 1) % NUM_COLORS;
    }
  }
  
  // Use current selected color for breathing effect
  CRGB breatheColor = colorOptions[currentColorIndex];
  breatheColor.fadeToBlackBy(255 - breatheBrightness);
  fill_solid(leds, NUM_LEDS, breatheColor);
}
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

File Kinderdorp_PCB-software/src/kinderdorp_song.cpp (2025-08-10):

#include "kinderdorp_song.h"

// Song State Variables
SongState songState = IDLE;
unsigned long songStepStartTime = 0;
unsigned long songDelayEnd = 0;
int songStep = 0;
bool noteCurrentlyPlaying = false;
bool inDelay = false;

void initSong() {
    songStep = 0;
    songState = PLAYING_SONG;
    songStepStartTime = millis();
    noteCurrentlyPlaying = false;
    inDelay = false;
    
    Serial.println("Starting Kinderdorp song");
}

void stopSong() {
    songState = IDLE;
    noTone(BUZZER_PIN);
    Serial.println("Song stopped");
}

void updateSongCore() {
    if (songState != PLAYING_SONG) return;
    
    unsigned long currentTime = millis();
    
    // Handle delay periods
    if (inDelay) {
        if (currentTime >= songDelayEnd) {
            inDelay = false;
            songStep++;
        }
        return;
    }
    
    // Execute the current song step
    playKinderdorpSong();
}

void playKinderdorpSong() {
    unsigned long currentTime = millis();
    
    switch (songStep) {
        // First verse - repeat
        // Edegc
        case 0: tone(BUZZER_PIN, NOTE_E4, SIXTEENTH); songDelayEnd = currentTime + EIGHTH; inDelay = true; break;
        case 1: tone(BUZZER_PIN, NOTE_D4, SIXTEENTH); songDelayEnd = currentTime + EIGHTH; inDelay = true; break;
        case 2: tone(BUZZER_PIN, NOTE_E4, SIXTEENTH); songDelayEnd = currentTime + EIGHTH; inDelay = true; break;
        case 3: tone(BUZZER_PIN, NOTE_G4, EIGHTH); songDelayEnd = currentTime + QUARTER; inDelay = true; break;
        case 4: tone(BUZZER_PIN, NOTE_C4, EIGHTH); songDelayEnd = currentTime + QUARTER; inDelay = true; break;
        case 5: songDelayEnd = currentTime + EIGHTH; inDelay = true; break; // Pause
        
        // Edegc
        case 6: tone(BUZZER_PIN, NOTE_E4, SIXTEENTH); songDelayEnd = currentTime + EIGHTH; inDelay = true; break;
        case 7: tone(BUZZER_PIN, NOTE_D4, SIXTEENTH); songDelayEnd = currentTime + EIGHTH; inDelay = true; break;
        case 8: tone(BUZZER_PIN, NOTE_E4, SIXTEENTH); songDelayEnd = currentTime + EIGHTH; inDelay = true; break;
        case 9: tone(BUZZER_PIN, NOTE_G4, EIGHTH); songDelayEnd = currentTime + QUARTER; inDelay = true; break;
        case 10: tone(BUZZER_PIN, NOTE_C4, EIGHTH); songDelayEnd = currentTime + QUARTER; inDelay = true; break;
        case 11: songDelayEnd = currentTime + EIGHTH; inDelay = true; break; // Pause
        
        // Eede
        case 12: tone(BUZZER_PIN, NOTE_E4, EIGHTH); songDelayEnd = currentTime + QUARTER; inDelay = true; break;
        case 13: tone(BUZZER_PIN, NOTE_E4, EIGHTH); songDelayEnd = currentTime + QUARTER; inDelay = true; break;
        case 14: tone(BUZZER_PIN, NOTE_E4, EIGHTH); songDelayEnd = currentTime + QUARTER; inDelay = true; break;
        case 15: tone(BUZZER_PIN, NOTE_D4, SIXTEENTH); songDelayEnd = currentTime + EIGHTH; inDelay = true; break;
        case 16: tone(BUZZER_PIN, NOTE_E4, HALF); songDelayEnd = currentTime + QUARTER; inDelay = true; break;
        case 17: songDelayEnd = currentTime + HALF; inDelay = true; break; // Long pause
        
        // Second verse - repeat
        // Edegc
        case 18: tone(BUZZER_PIN, NOTE_E4, SIXTEENTH); songDelayEnd = currentTime + EIGHTH; inDelay = true; break;
        case 19: tone(BUZZER_PIN, NOTE_D4, SIXTEENTH); songDelayEnd = currentTime + EIGHTH; inDelay = true; break;
        case 20: tone(BUZZER_PIN, NOTE_E4, SIXTEENTH); songDelayEnd = currentTime + EIGHTH; inDelay = true; break;
        case 21: tone(BUZZER_PIN, NOTE_G4, EIGHTH); songDelayEnd = currentTime + QUARTER; inDelay = true; break;
        case 22: tone(BUZZER_PIN, NOTE_C4, EIGHTH); songDelayEnd = currentTime + QUARTER; inDelay = true; break;
        case 23: songDelayEnd = currentTime + QUARTER; inDelay = true; break; // Pause
        
        // Continue with more song cases
        case 24: tone(BUZZER_PIN, NOTE_E4, SIXTEENTH); songDelayEnd = currentTime + EIGHTH; inDelay = true; break;
        case 25: tone(BUZZER_PIN, NOTE_D4, SIXTEENTH); songDelayEnd = currentTime + EIGHTH; inDelay = true; break;
        case 26: tone(BUZZER_PIN, NOTE_E4, SIXTEENTH); songDelayEnd = currentTime + EIGHTH; inDelay = true; break;
        case 27: tone(BUZZER_PIN, NOTE_G4, EIGHTH); songDelayEnd = currentTime + QUARTER; inDelay = true; break;
        case 28: tone(BUZZER_PIN, NOTE_C4, EIGHTH); songDelayEnd = currentTime + QUARTER; inDelay = true; break;
        case 29: songDelayEnd = currentTime + QUARTER; inDelay = true; break; // Pause
        
        // Eede
        case 30: tone(BUZZER_PIN, NOTE_E4, EIGHTH); songDelayEnd = currentTime + QUARTER; inDelay = true; break;
        case 31: tone(BUZZER_PIN, NOTE_E4, EIGHTH); songDelayEnd = currentTime + QUARTER; inDelay = true; break;
        case 32: tone(BUZZER_PIN, NOTE_E4, EIGHTH); songDelayEnd = currentTime + QUARTER; inDelay = true; break;
        case 33: tone(BUZZER_PIN, NOTE_D4, SIXTEENTH); songDelayEnd = currentTime + EIGHTH; inDelay = true; break;
        case 34: tone(BUZZER_PIN, NOTE_E4, HALF); songDelayEnd = currentTime + QUARTER; inDelay = true; break;
        case 35: songDelayEnd = currentTime + HALF; inDelay = true; break; // Long pause
        
        // Hutje hier,
        case 36: tone(BUZZER_PIN, NOTE_F4, SIXTEENTH); songDelayEnd = currentTime + EIGHTH; inDelay = true; break;
        case 37: tone(BUZZER_PIN, NOTE_F4, EIGHTH); songDelayEnd = currentTime + QUARTER; inDelay = true; break;
        case 38: tone(BUZZER_PIN, NOTE_A4, HALF); songDelayEnd = currentTime + HALF; inDelay = true; break;
        case 39: songDelayEnd = currentTime + QUARTER; inDelay = true; break; // Pause
        
        // Hutje daar,
        case 40: tone(BUZZER_PIN, NOTE_E4, SIXTEENTH); songDelayEnd = currentTime + EIGHTH; inDelay = true; break;
        case 41: tone(BUZZER_PIN, NOTE_E4, EIGHTH); songDelayEnd = currentTime + QUARTER; inDelay = true; break;
        case 42: tone(BUZZER_PIN, NOTE_G4, HALF); songDelayEnd = currentTime + HALF; inDelay = true; break;
        case 43: songDelayEnd = currentTime + QUARTER; inDelay = true; break; // Pause
        
        // Kinderdorp is bijna klaar - Continue with more cases...
        case 44: tone(BUZZER_PIN, NOTE_G4, EIGHTH); songDelayEnd = currentTime + EIGHTH; inDelay = true; break;
        case 45: tone(BUZZER_PIN, NOTE_G4, EIGHTH); songDelayEnd = currentTime + SIXTEENTH; inDelay = true; break;
        case 46: tone(BUZZER_PIN, NOTE_G4, EIGHTH); songDelayEnd = currentTime + EIGHTH; inDelay = true; break;
        case 47: tone(BUZZER_PIN, NOTE_F4, EIGHTH); songDelayEnd = currentTime + EIGHTH; inDelay = true; break;
        case 48: tone(BUZZER_PIN, NOTE_E4, EIGHTH); songDelayEnd = currentTime + EIGHTH; inDelay = true; break;
        case 49: tone(BUZZER_PIN, NOTE_F4, EIGHTH); songDelayEnd = currentTime + SIXTEENTH; inDelay = true; break;
        case 50: tone(BUZZER_PIN, NOTE_G4, HALF); songDelayEnd = currentTime + HALF; inDelay = true; break;
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

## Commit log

2025-05-12 updated all 3d models
    [Kinderdorp_PCB.kicad_pcb]
2025-05-12 added AAA box 3d model and reference images
    [Kinderdorp_PCB.kicad_pcb, Kinderdorp_PCB.kicad_sch]
2025-05-12 imported/created thumb design
    [Kinderdorp_PCB.kicad_pcb, Kinderdorp_PCB.kicad_sch]
2025-07-26 created new oultine for pcb
    [Kinderdorp_PCB.kicad_pcb]
2025-07-26 fixed naming designators
    [Kinderdorp_PCB.kicad_pcb, Kinderdorp_PCB.kicad_sch]
2025-07-26 fixed annotation again
    [Kinderdorp_PCB.kicad_pcb, Kinderdorp_PCB.kicad_sch]
2025-07-26 finished layout
    [Kinderdorp_PCB.kicad_pcb, Kinderdorp_PCB.kicad_sch]
2025-07-26 updated logo
    [Kinderdorp_PCB.kicad_pcb, Kinderdorp_PCB.kicad_sch]
2025-07-26 saving changes to W&T logo
    [Kinderdorp_PCB.kicad_pcb]
2025-07-26 added media files and finished routing
    [Kinderdorp_PCB.kicad_pcb]
2025-07-27 Finalized design
    - added esd protection
    - minor silkscreen improvements
    [Kinderdorp_PCB.kicad_pcb, Kinderdorp_PCB.kicad_sch]
2025-07-27 minor changes to files and added production files
    [Kinderdorp_PCB.kicad_pcb, Kinderdorp_PCB.kicad_sch, bom.csv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]
2025-07-27 updated silkscreen
    [Kinderdorp_PCB.kicad_pcb]
2025-07-27 made some more change to silkscreen
    (because of my borderline OCD)
    [Kinderdorp_PCB.kicad_pcb]
2025-07-27 moved board to centre
    [Kinderdorp_PCB.kicad_pcb]
2025-08-07 Working on software for the PCB
2025-08-08 Manual song creation in arduino and added audio files
2025-08-08 FIxed end of song
    [main.cpp]
2025-08-09 fixed button design error
    [Kinderdorp_PCB.kicad_pcb, Kinderdorp_PCB.kicad_sch]
2025-08-10 added more lighting effects and updated i2c on pcb (header)
    [Kinderdorp_PCB.kicad_pcb, Kinderdorp_PCB.kicad_sch]
2025-08-10 V1.0 of code
    - music
    - light effects
    - serial monitor
    - battery detection
2025-08-10 updated PCB to V1.1
    removed cr2032 (this is not viable with the current draw of the board)
    [Kinderdorp_PCB.kicad_pcb, Kinderdorp_PCB.kicad_sch]
